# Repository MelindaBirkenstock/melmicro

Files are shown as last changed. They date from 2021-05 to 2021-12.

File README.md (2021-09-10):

This is a drop-in pro micro replacement for any board that accepts a pro micro. The name is a misonmer as the "melmicro" is actually usb-c.
# MelMicro supports both qfn and qfp mcus, i'm not liable for anything.

THIS MUST BE RAN AS A 4 LAYER.

STEPS.
1. Download "melmicro-panel.zip", This is the gerber file for melmicro panels that is required as jlc will not assemble single boards.
2. Navigate to the "Bom and Placement Files" folder, download the BOM for either "panel-au.csv" or "panel-mu.csv". 
3. Download "panel-top-pos.csv", this is your placement file for the pcb manufacturer.
These are the files necessary for pcba.

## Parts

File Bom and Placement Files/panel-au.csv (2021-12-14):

Comment | Designator | Footprint | JLCPCB Part #（optional）
500mA | F1,F1 | 1206 | C135336
HRO-TYPE-C-31-M-12 | USB1,USB1 | TYPE-C-31_L8.94_W7.3 | C165948
Crystal_GND24_Small | Y1,Y1 | SMD-CRY-3225_4P | C13738
22pF | C1,C2,C1,C2 | 402 | C1555
0.1uF | C3,C4,C5,C3,C4,C5 | 402 | C1525
10uF | C6,C6 | 402 | C15525
1uF | C7,C7 | 402 | C52923
10k | R1,R6,R1,R6 | 402 | C25744
5.1k | R2,R5,R2,R5 | 402 | C25905
22k | R3,R4,R3,R4 | 402 | C25092
ATmega32U4-AU | U2,U2 | TQFP-44_10.0x10.0x0.8P | C44854

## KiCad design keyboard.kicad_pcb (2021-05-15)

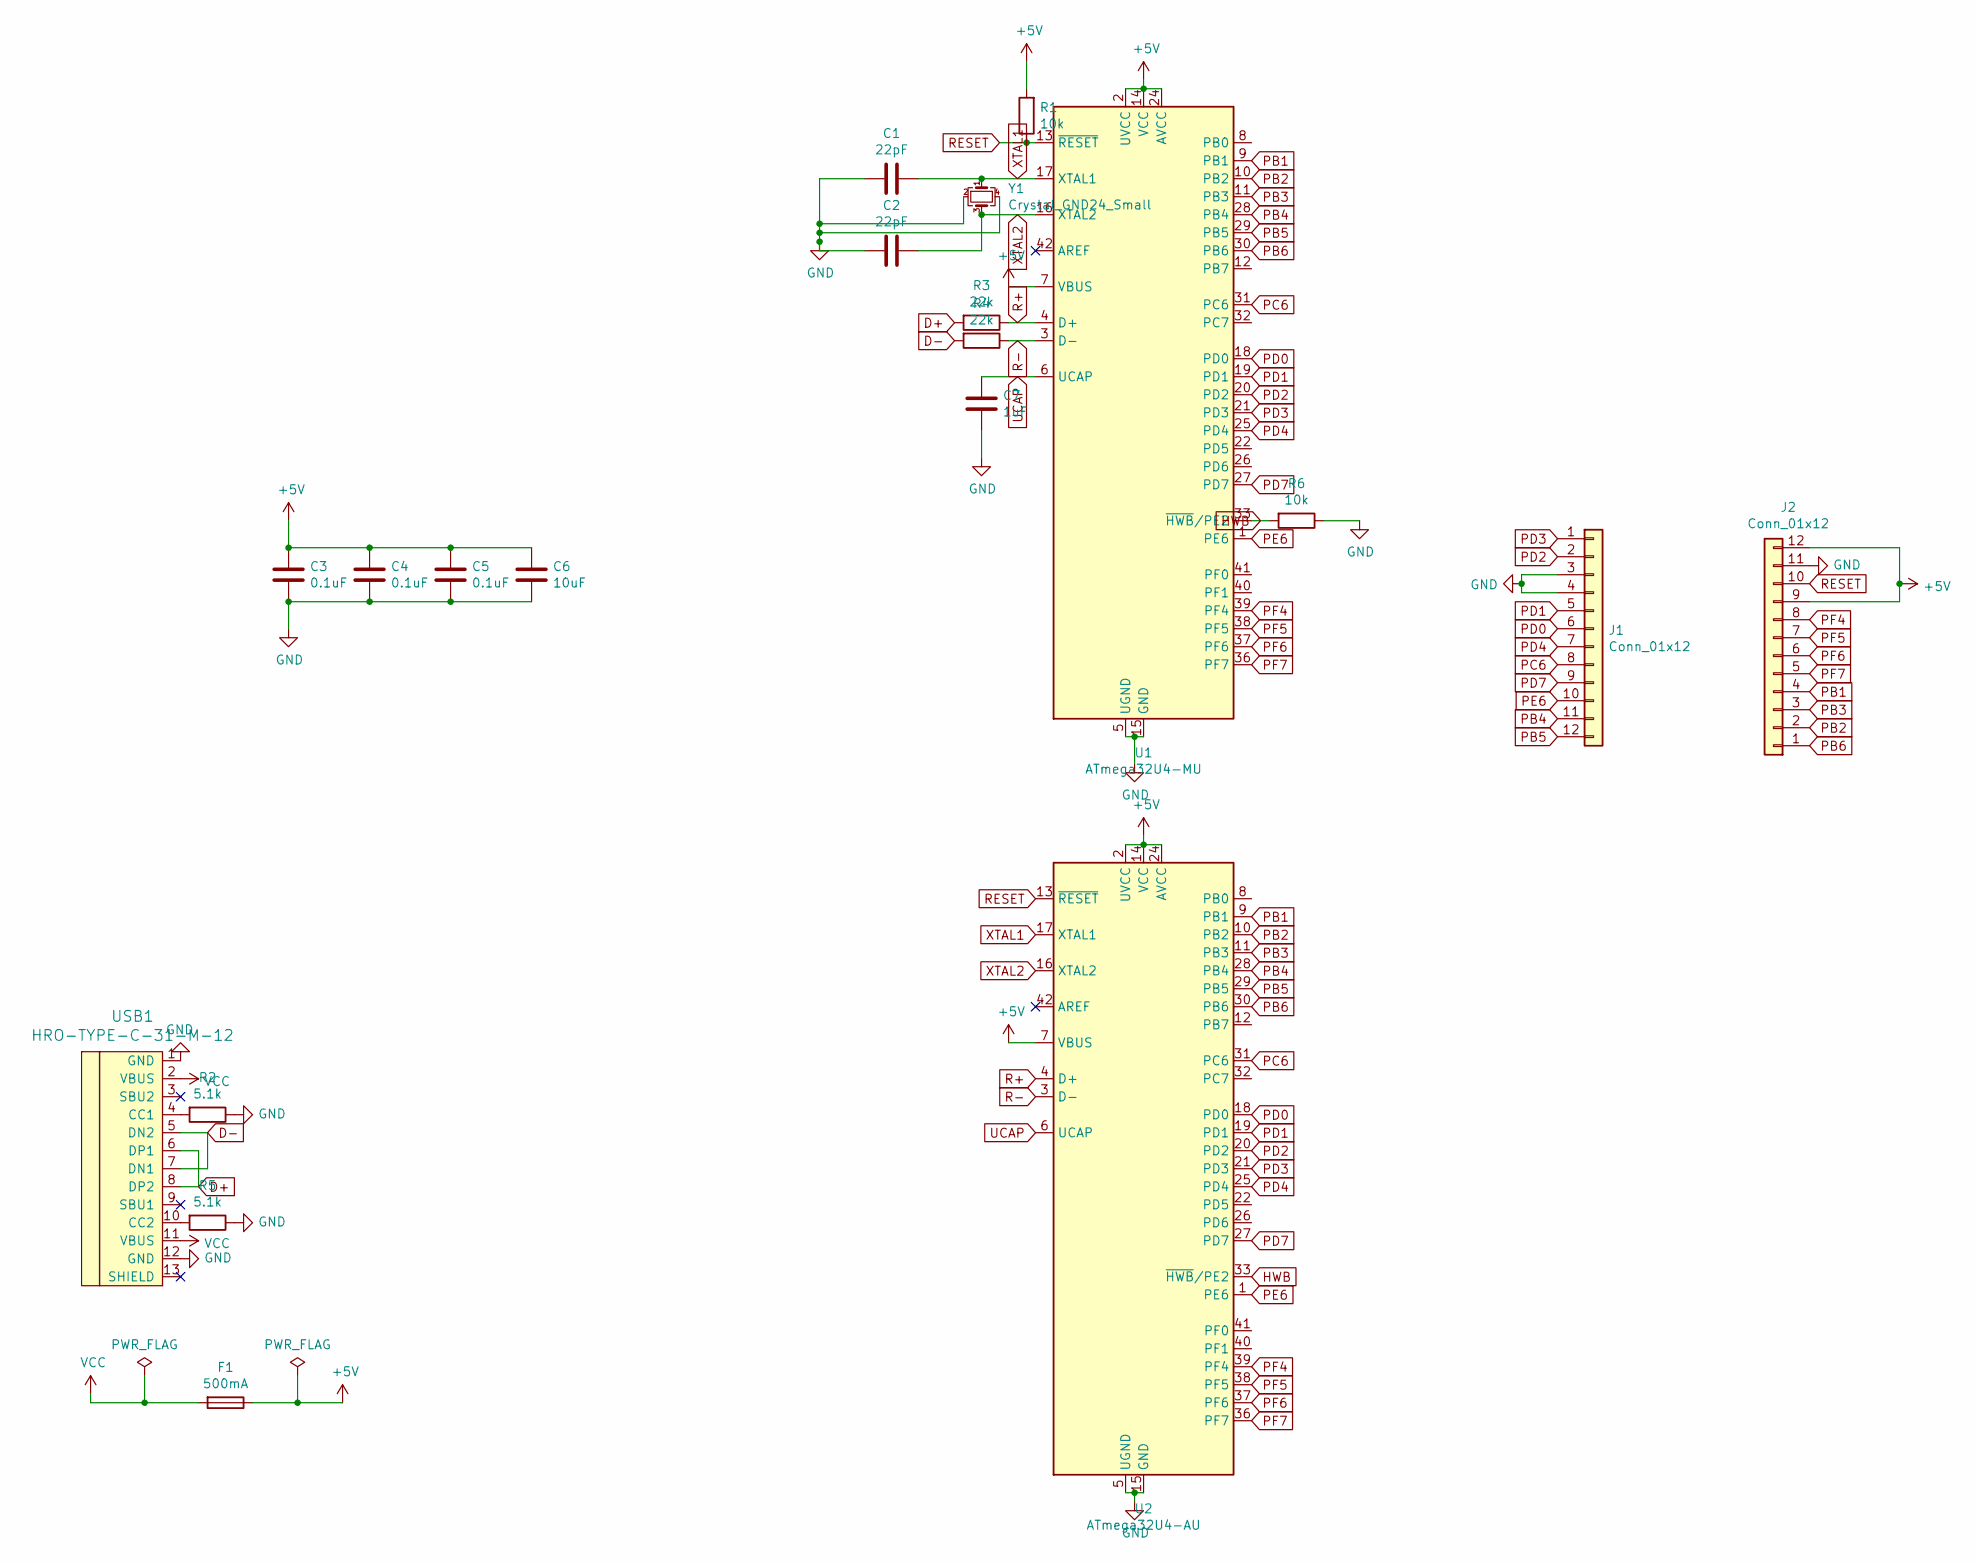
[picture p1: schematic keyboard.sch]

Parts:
C1, C2: 22pF; C_0402_1005Metric
C3, C4, C5: 0.1uF; C_0402_1005Metric
C6: 10uF; C_0402_1005Metric
C7: 1uF; C_0402_1005Metric
F1: 500mA; Fuse_1206_3216Metric
J1, J2: Conn_01x12; PinSocket_1x12_P2.54mm_Vertical
R1, R6: 10k; C_0402_1005Metric
R2, R5: 5.1k; C_0402_1005Metric
R3, R4: 22k; C_0402_1005Metric
U1: ATmega32U4-MU; QFN-44-1EP_7x7mm_P0.5mm_EP5.2x5.2mm
U2: ATmega32U4-AU; TQFP-44_10x10mm_P0.8mm
USB1: HRO-TYPE-C-31-M-12; HRO-TYPE-C-31-M-12-Assembly
Y1: Crystal_GND24_Small; Crystal_SMD_3225-4Pin_3.2x2.5mm

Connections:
+5V: C3.1, C4.1, C5.1, C6.1, F1.1, J2.9, J2.12, R1.2, U1.2 (UVCC), U1.7 (VBUS), U1.14 (VCC), U1.24 (AVCC), U1.34 (VCC), U1.44 (AVCC), U2.2 (UVCC), U2.7 (VBUS), U2.14 (VCC), U2.24 (AVCC), U2.34 (VCC), U2.44 (AVCC)
D+: R3.2, USB1.6 (DP1), USB1.8 (DP2)
D-: R4.2, USB1.5 (DN2), USB1.7 (DN1)
GND: C1.2, C2.2, C3.2, C4.2, C5.2, C6.2, C7.2, J1.3, J1.4, J2.11, R2.1, R5.1, R6.1, U1.5 (UGND), U1.15 (GND), U1.23 (GND), U1.35 (GND), U1.43 (GND), U1.45 (GND), U2.5 (UGND), U2.15 (GND), U2.23 (GND), U2.35 (GND), U2.43 (GND), USB1.1 (GND), USB1.12 (GND), Y1.2, Y1.4
HWB: R6.2, U1.33 (~HWB~/PE2), U2.33 (~HWB~/PE2)
unnamed: R2.2, USB1.4 (CC1)
unnamed: R5.2, USB1.10 (CC2)
PB1: J2.4, U1.9 (PB1), U2.9 (PB1)
PB2: J2.2, U1.10 (PB2), U2.10 (PB2)
PB3: J2.3, U1.11 (PB3), U2.11 (PB3)
PB4: J1.11, U1.28 (PB4), U2.28 (PB4)
PB5: J1.12, U1.29 (PB5), U2.29 (PB5)
PB6: J2.1, U1.30 (PB6), U2.30 (PB6)
PC6: J1.8, U1.31 (PC6), U2.31 (PC6)
PD0: J1.6, U1.18 (PD0), U2.18 (PD0)
PD1: J1.5, U1.19 (PD1), U2.19 (PD1)
PD2: J1.2, U1.20 (PD2), U2.20 (PD2)
PD3: J1.1, U1.21 (PD3), U2.21 (PD3)
PD4: J1.7, U1.25 (PD4), U2.25 (PD4)
PD7: J1.9, U1.27 (PD7), U2.27 (PD7)
PE6: J1.10, U1.1 (PE6), U2.1 (PE6)
PF4: J2.8, U1.39 (PF4), U2.39 (PF4)
PF5: J2.7, U1.38 (PF5), U2.38 (PF5)
PF6: J2.6, U1.37 (PF6), U2.37 (PF6)
PF7: J2.5, U1.36 (PF7), U2.36 (PF7)
R+: R3.1, U1.4 (D+), U2.4 (D+)
R-: R4.1, U1.3 (D-), U2.3 (D-)
RESET: J2.10, R1.1, U1.13 (~RESET), U2.13 (~RESET)
UCAP: C7.1, U1.6 (UCAP), U2.6 (UCAP)
VCC: F1.2, USB1.2 (VBUS), USB1.11 (VBUS)
XTAL1: C1.1, U1.17 (XTAL1), U2.17 (XTAL1), Y1.1
XTAL2: C2.1, U1.16 (XTAL2), U2.16 (XTAL2), Y1.3

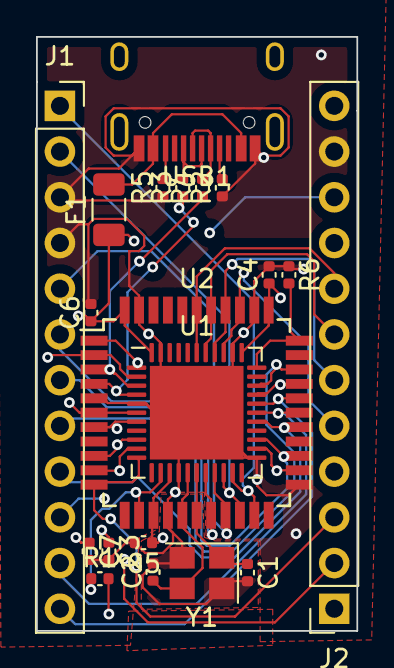
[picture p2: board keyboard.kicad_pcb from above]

Board: 4 copper layers, 17.8 x 33.0 mm, 20 parts (0 on the bottom side), 32 nets.

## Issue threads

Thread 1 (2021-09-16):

JLC Bom Updates

MelindaBirkenstock, 2021-09-16:
Recently, JLC updated their BOM requirements to be stricter, as such the ones currently in the repo do not work.

Closed 2021-12-14.

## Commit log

2021-03-17 second push
    [keyboard-B_Adhes.gbr, keyboard-B_CrtYd.gbr, keyboard-B_Fab.gbr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]
2021-03-17 added ground vias to link the seperate ground planes
    [keyboard.kicad_pcb]
2021-03-17 fixed zone issues
    [keyboard.kicad_pcb]
2021-05-15 Added Bom and Placement files, courtesy of Taylor. There is also gerbers for panelized boards.
    [keyboard.kicad_pcb, panel-au.csv, panel-mu.csv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]
2021-09-10 Updated fuse LCSC number to a proper fuse.
    [panel-au.csv]
2021-09-10 Updated fuse to a proper fuse.
    [panel-mu.csv]
2021-12-13 Update files to match JCLPCB requirements
    [panel-au.csv, panel-mu.csv]
